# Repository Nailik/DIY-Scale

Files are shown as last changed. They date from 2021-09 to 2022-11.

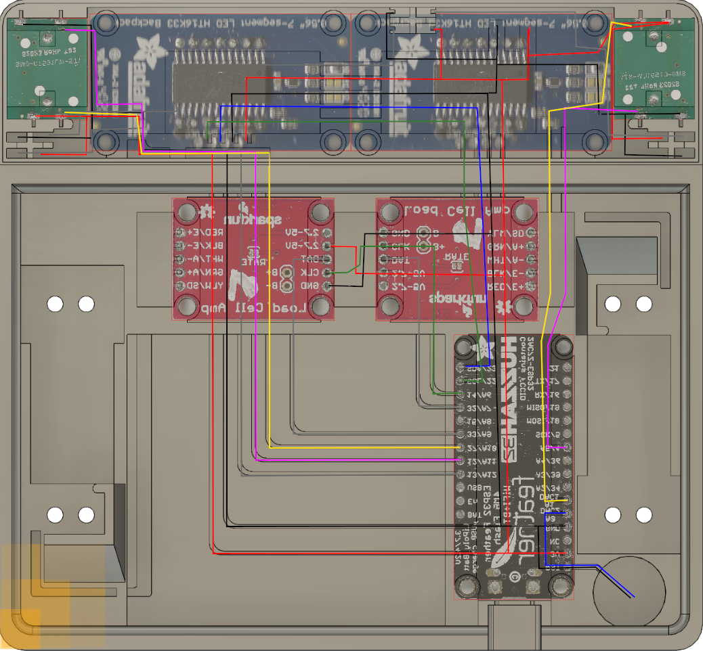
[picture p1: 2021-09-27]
documentation/Wiring_image_2.png

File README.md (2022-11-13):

# DIY-Scale
Very thin DIY scale with bluetooth and wifi - intended to be used with a coffee machine.

More information can be found on my [Website](https://kilian-eller.de/en/projects/diy-scale)

There are currently some issues that should be resolved.
<ul>
 <li> Sometimes the scale freezes when connected to usb power
 <li> Weight drifts while plugged in
</ul>

More information about this is in the "Projects" Tab.

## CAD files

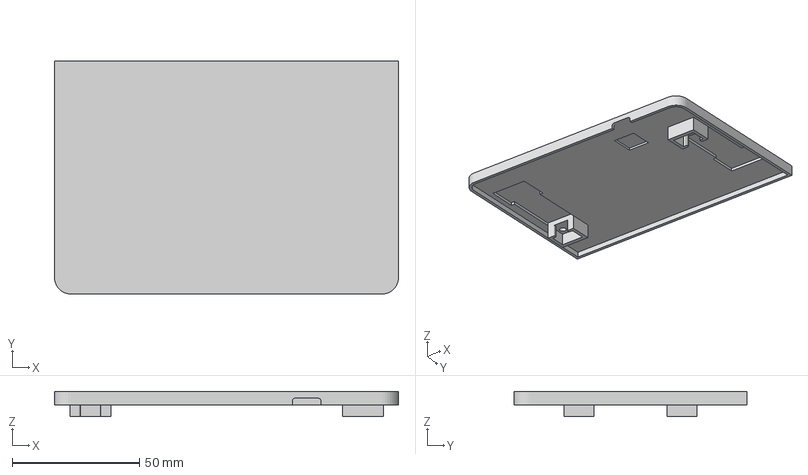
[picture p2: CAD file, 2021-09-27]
3d Model/top.3mf
135.0 x 91.5 x 9.85 mm

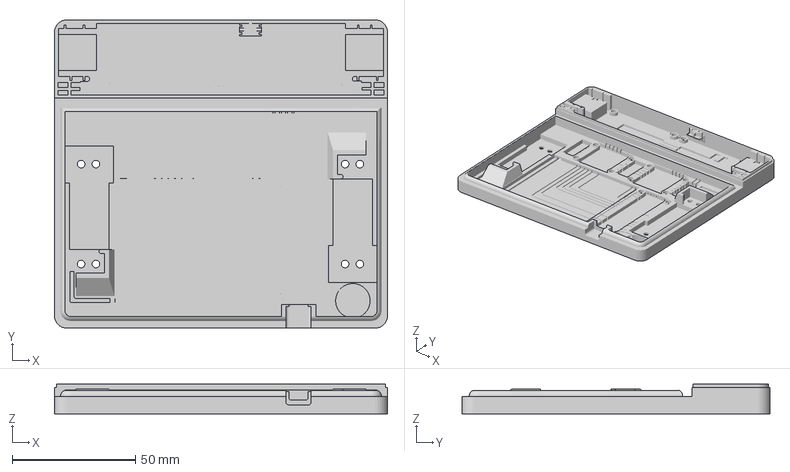
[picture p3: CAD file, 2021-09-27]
3d Model/bottom_case.3mf
135.0 x 125.0 x 12.2 mm

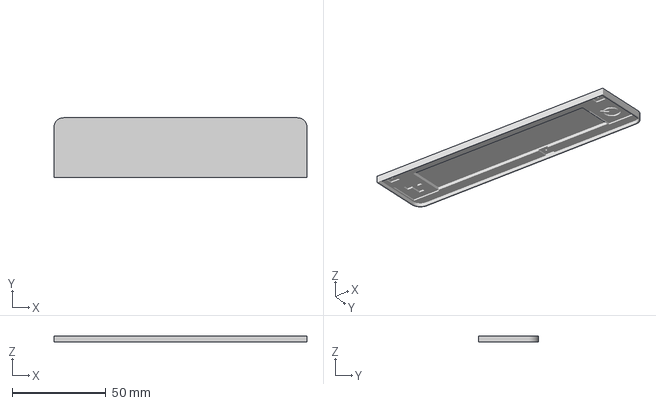
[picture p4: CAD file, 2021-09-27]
3d Model/displaycover.3mf
135.0 x 31.8 x 3.35 mm

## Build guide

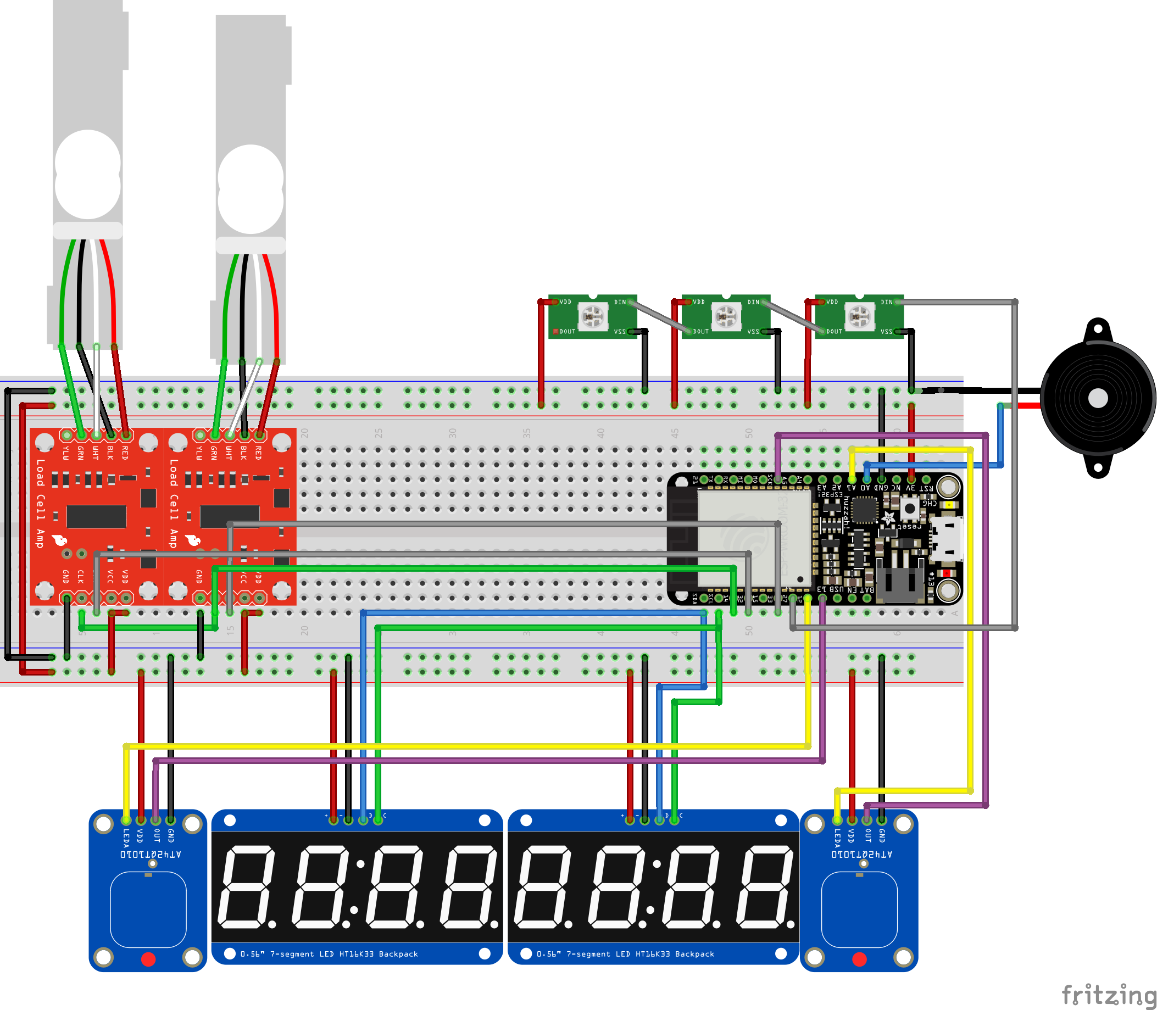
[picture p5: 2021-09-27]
documentation/fritzing_wiring.png

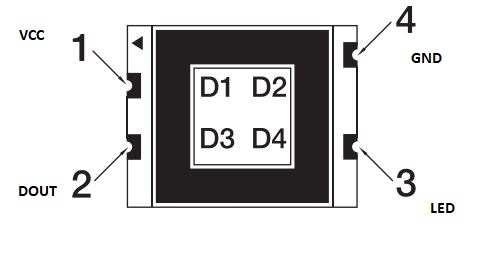
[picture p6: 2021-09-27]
documentation/button_wiring.JPG

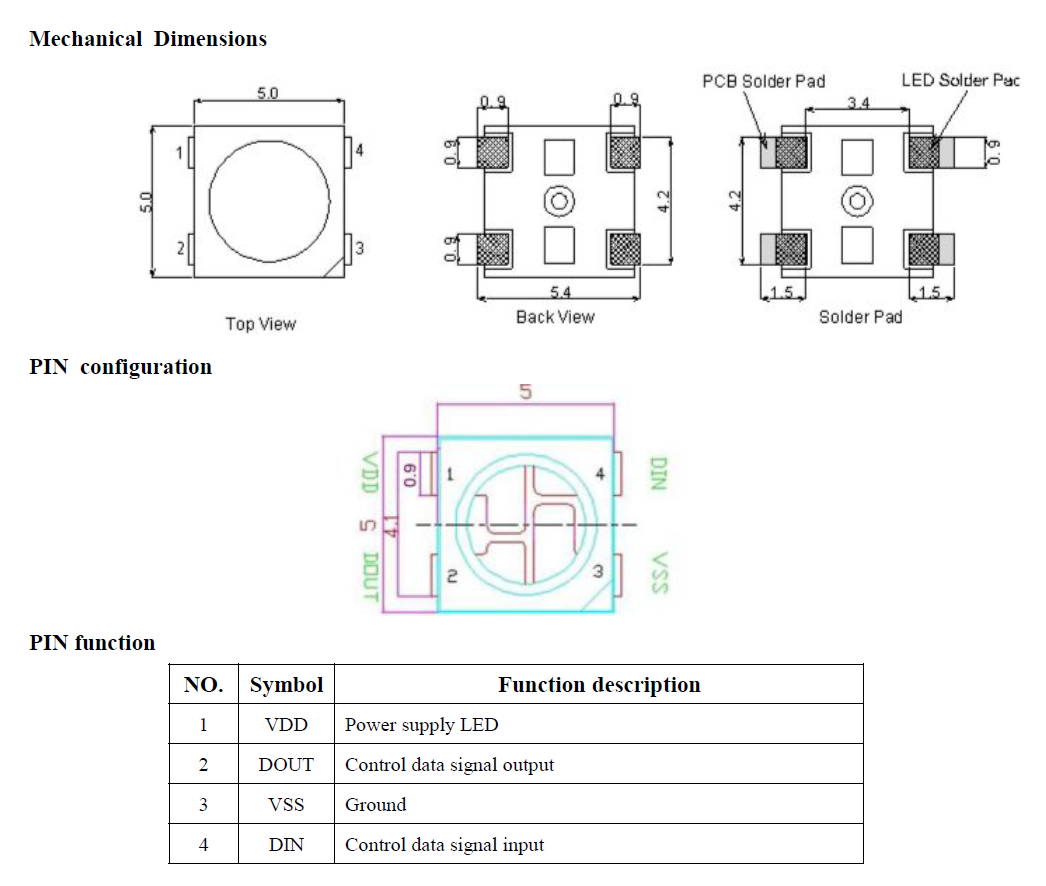
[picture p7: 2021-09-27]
documentation/led_wiring.png

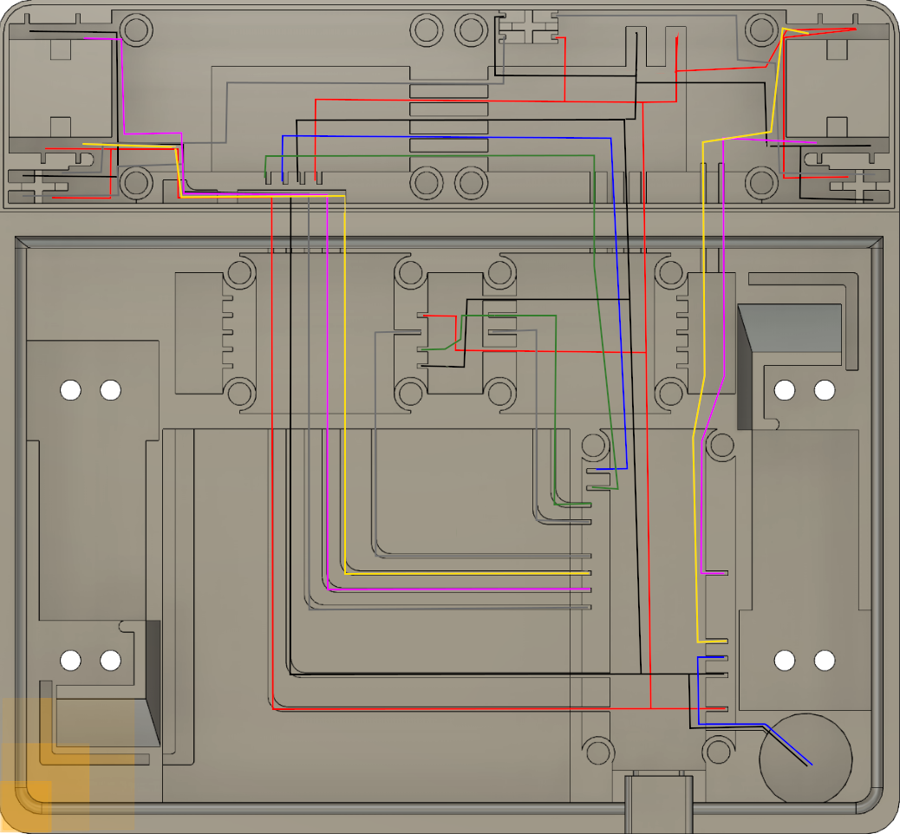
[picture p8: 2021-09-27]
documentation/Wiring_image_1.png

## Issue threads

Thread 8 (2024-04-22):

3D Model not available for download anymore

FelixMau, 2024-04-22:
Dear Kilian Eller,

I want to try to copy your approach on the DIY bluetooth scale. I want to combine with brew by weight by [tatemazer](https://github.com/tatemazer/AcaiaArduinoBLE)

When starting I quickly realised the 500g weighcells (1 is available but your model requires 2) are not available for me at the moment and it seems it is unkown when they will restock therfore I want to adjust the 3D Models to fit the 1kg cells that are way cheaper as well.

Unfortunately it seems your commenting function on the website is broken as well. Because this is not a really code related issue I wanted to post there but my comments to not appear on the website.

Since your project aged a little I also wondered if you would recommend building a diy scale and if you made any adjustments that maybe are not documented?

Kind regards, Felix

Nailik, 2024-04-22:
Hi thanks for the comment - i'll rarely update my website but will look into it.

Depending on your use case 1 kg weightcellt might have a too high error percentage.

If i would built it nowadays i would update a lot of things because i had various issues.
- Built a single board and let it manufacure by jdbc or some other manufactuerer, because the wiring was really hard.
- The software has issues when the board is charged via usb and hangs up
- There was weight creeping - meaning if you let a certain weight sit on it for a longer amount of time the readings will get off and increase without change (This might also be related to bad wiring and using 2 Hx711)

So i would probably use this only as a start point to have an idea what's needed and start from scratch by first building a rudimentary board with a load cell and test around how to fix creeping issues and get reliable readings. You also have to watch out that readings can be off when you place and object on the corner of your top plate because the very sensitive weight cells could bind in a certain direction.

Nailik, 2024-04-22:
Btw you should be able to download the 3d model from the source code https://github.com/Nailik/DIY-Scale/tree/master/3d%20Model

Nailik, 2024-04-22:
Actually the comment function did work but i made it so i have to accept comments in order to not get spammed or some maleware links etc :)

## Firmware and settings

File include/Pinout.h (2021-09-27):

//
// Created by kilian on 01.08.2021.
//

/**
 * saves all HUZZAH 32 pins for easy lookup and also whats connected to it in this project
 */

#ifndef PROJECT_PINOUT_H
#define PROJECT_PINOUT_H

#define PIN_STATUS_LED      13 //A12
#define PIN_SOUND           26 //A0
#define PIN_BTN_TARA        27 //A10
#define PIN_BTN_TARA_LED    12 //A11
#define PIN_BTN_TIMER       25 //A1
#define PIN_BTN_TIMER_LED   4  //A5
#define PIN_SENSOR_0        32 //A7 left sensor (close at esp)
#define PIN_SENSOR_1        33 //A9 right sensor
#define PIN_HX711_CLOCK_0   14 //A6
#define PIN_HX711_CLOCK_1   14 //A8

#define ADDRESS_DISPLAY_0   0x70
#define ADDRESS_DISPLAY_1   0x71

#define IND_BTN_TARE_STATUS_LED    0
#define IND_BTN_BAT_LED            1
#define IND_BTN_TIMER_STATUS_LED   2

#define BAT_PIN 35 //A13
#define BAT_MIN 3000 //mV
#define BAT_MAX 4200 //mV

// https://de.decentespresso.com/scale_api
#define CMD_TARE            0x10
#define CMD_DISPLAY_ON      0xED
#define CMD_DISPLAY_OFF     0xEE

#endif //PROJECT_PINOUT_H

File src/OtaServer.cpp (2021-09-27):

//
// Created by kilian on 10.08.2021.
//

#include <OtaServer.h>


/**
 * Creates a webserver to host a website for Settings and Calibration
 * html files are stored in SPIFFS
 */
static AsyncWebServer otaServer_server(80);
static DNSServer dnsServer;

/**
 * setup dns, routes, start server and open Spiffs files for webserver
 */
void OtaServer::setup() {
    Logger::log("otaserver setup");

    setupDns();
    // Initialize SPIFFS
    SPIFFS.begin(false);
    setupRoutes();
    otaServer_server.begin();
}


/**
 * Start Dns Server, set Skale Internal network IP to 192.168.0.1
 * And Starts a MDNS Server to be found in networks
 *
 * Depends on Network how fast and reliable the Skale can be found
 */
void OtaServer::setupDns() {
    Logger::log("otaserver setupDns");

    dnsServer.start(53, "*", IPAddress(192, 168, 0, 1));
    MDNS.begin("scale");
    MDNS.addService("http", "tcp", 80);
}

/**
 * process dns requests
 */
void OtaServer::loop() {
    dnsServer.processNextRequest();
}

/**
 * routes for web server to answer on
 */
void OtaServer::setupRoutes() {
    Logger::log("otaserver setupRoutes");

    setupFileRoutes();
    setupDataRequests();
    setupDataPosts();
    setupCalibration();

    //default when site is not found
    otaServer_server.onNotFound([](AsyncWebServerRequest *request) {
        Logger::log("404 server request " + request->url());
        request->send(404, "text/html", "Site not found");
    });


    //cancel the calibration (only if calibration is running)
    otaServer_server.on("/doUpdate", HTTP_POST,
                        [](AsyncWebServerRequest *request) {},
                        [](AsyncWebServerRequest *request, const String &filename, size_t index, uint8_t *data, size_t len, bool final) {
                            if (!index) {
                                // if filename includes spiffs, update the spiffs partition
                                int cmd = (filename.indexOf("spiffs") > -1) ? U_PART : U_FLASH;
                                if (!Update.begin(UPDATE_SIZE_UNKNOWN, cmd)) {
                                    Update.printError(Serial);
                                    return;
                                }
                            }

                            if (Update.write(data, len) != len) {
                                Update.printError(Serial);
                                return;
                            }

                            request->send(200, "text/plane");
                            //print update process
                            Logger::log("Update Progress: " + String((int) ((Update.progress() * 100) / Update.size())) + " %");

                            if (final) {
                                AsyncWebServerResponse *response = request->beginResponse(302, "text/plain", "rebooting");
                                response->addHeader("Refresh", "20");
                                response->addHeader("Location", "/");
                                request->send(response);
                                if (!Update.end(true)) {
                                    Update.printError(Serial);
                                } else {
                                    Logger::log("Update complete");
                                    Serial.flush();
                                    ESP.restart();
                                }
                            }
                        });
}

/**
 * Setup Routes for files (html, css, js)
 */
void OtaServer::setupFileRoutes() {
    otaServer_server.on("/", HTTP_GET, [](AsyncWebServerRequest *request) {
        Logger::log("otaserver index");
        sendFileResponse("/html/index.html", "text/html", request);
    });

    otaServer_server.on("/index.html", HTTP_GET, [](AsyncWebServerRequest *request) {
        Logger::log("otaserver index");
        sendFileResponse("/html/index.html", "text/html", request);
    });

    otaServer_server.on("/settings.html", HTTP_GET, [](AsyncWebServerRequest *request) {
        Logger::log("otaserver settings");
        sendFileResponse("/html/settings.html", "text/html", request);
    });

    otaServer_server.on("/calibrate.html", HTTP_GET, [](AsyncWebServerRequest *request) {
        Logger::log("otaserver calibrate");
        sendFileResponse("/html/calibrate.html", "text/html", request);
    });

    otaServer_server.on("/update.html", HTTP_GET, [](AsyncWebServerRequest *request) {
        Logger::log("otaserver update");
        sendFileResponse("/html/update.html", "text/html", request);
    });

    otaServer_server.on("/bootstrap/bootstrap.min.css", HTTP_GET, [](AsyncWebServerRequest *request) {
        Logger::log("otaserver bootstrap css");
        sendFileResponse("/bootstrap/bootstrap.min.css", "text/css", request);
    });

    otaServer_server.on("/bootstrap/bootstrap.min.js", HTTP_GET, [](AsyncWebServerRequest *request) {
        Logger::log("otaserver bootstrap");
        sendFileResponse("/bootstrap/bootstrap.min.js", "text/js", request);
    });

    otaServer_server.on("/bootstrap/jquery.min.js", HTTP_GET, [](AsyncWebServerRequest *request) {
        Logger::log("otaserver jquery");
        sendFileResponse("/bootstrap/jquery.min.js", "text/js", request);
    });
}

/**
 * sends file as response to request automaticall uses gzip file if client accepts it
 *
 * @param uri String to path
 * @param type Type of file data
 * @param request request pointer
 */
void OtaServer::sendFileResponse(const String &uri, const String &type, AsyncWebServerRequest *request) {
    if (request->hasHeader("Accept-Encoding") && request->getHeader("Accept-Encoding")->value().indexOf("gzip") != -1) {
        //check if accepts gzip
        AsyncWebServerResponse *response = request->beginResponse(SPIFFS, uri + ".gz", type);
        //add header because there is a bug where header is maybe not set
        response->addHeader("Content-Encoding", "gzip");
        request->send(response);
    } else {
        request->send(SPIFFS, uri, type);
    }
}
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

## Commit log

2021-09-27 initial upload
    [Configuration.h, Wiring.fzz, bottom_case.3mf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]
2021-09-27 added 3f model
    [bottom_case.3mf, displaycover.3mf, top.3mf]
